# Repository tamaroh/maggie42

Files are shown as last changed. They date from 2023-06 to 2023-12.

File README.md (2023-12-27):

# maggie42
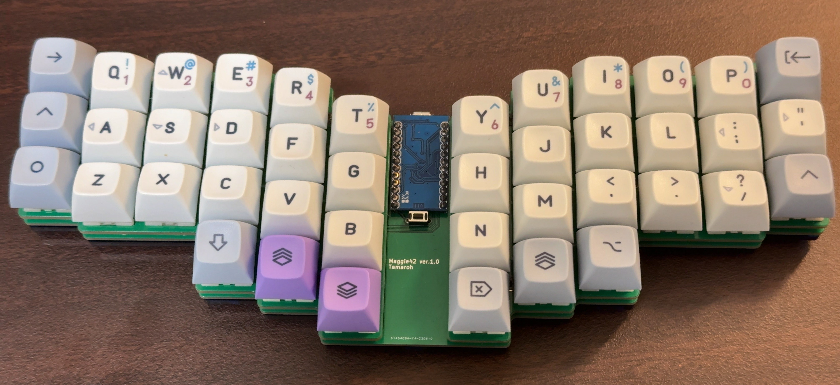
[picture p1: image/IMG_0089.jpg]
maggie42

maggie42は  
カスタムキーボードです。
- 左右対称カラムスタッガード
- 自然にハの字に手が配置される
- 傾けないレイアウトでキーの隙間がない
- 小指から弧を描く配列
- Pro Microに対応
- All 1Uレイアウト

## 必要なもの
|品名|数量|備考|入手先|
|----|----|----|----|
|PCB|1枚|
|キープレート|2枚|裏表はありません|
|ボトムプレート|1枚|
|M2ネジ 5mm|20本||遊舎工房など
|M2スペーサー 7mm|10個||遊舎工房など
|Pro Micro|1個|すべての互換品については動作を保障しません*|遊舎工房など
|ピンヘッダー|12Pin x 2個|コンスルー対応|遊舎工房など
|タクトスイッチ|1個||遊舎工房など
|USBケーブル|1本||遊舎工房など
|ダイオード|42個|SMD/スルーホール対応|遊舎工房など
|キーソケット|42個|Cherry MX互換のみ対応|遊舎工房など
|キースイッチ|42個|Cherry MX互換のみ対応|遊舎工房など
|キーキャップ|セット|すべて1Uです|遊舎工房など

* 厚さの異なるPro Micro互換品（USB-Cコネクタのタイプ）などの場合、コンスルーでは動作を保障できません。
  確実に接続できるピンヘッダ接続をおすすめします。

## 必要な工具
- はんだごて
- コテ台、コテ先クリーナー
- はんだ
- 精密ドライバー
- ピンセット

## 必要なソフトウェア
- [qmk toolbox](https://github.com/qmk/qmk_toolbox/releases)

## 制作手順
手順は人により異なりますが
1. Pro Microにファームウェアを書き込みます。
  - QMK Toolboxを起動し、書き込むファームウェア（下記参照）を選択しておきます。
  - USBをPCに接続して、リセットスイッチを押します。
  - 書き込み可能状態になったら、Flashボタンをクリックして書き込みます。
  - 書き込みが完了したらUSBケーブルを接続し直します。
2. ダイオードを半田付けします。SMDの場合縦線が入っている方の端子、スルーホールの場合黒い線がある方の端子を、基板上の縦線がある側に接続してください。
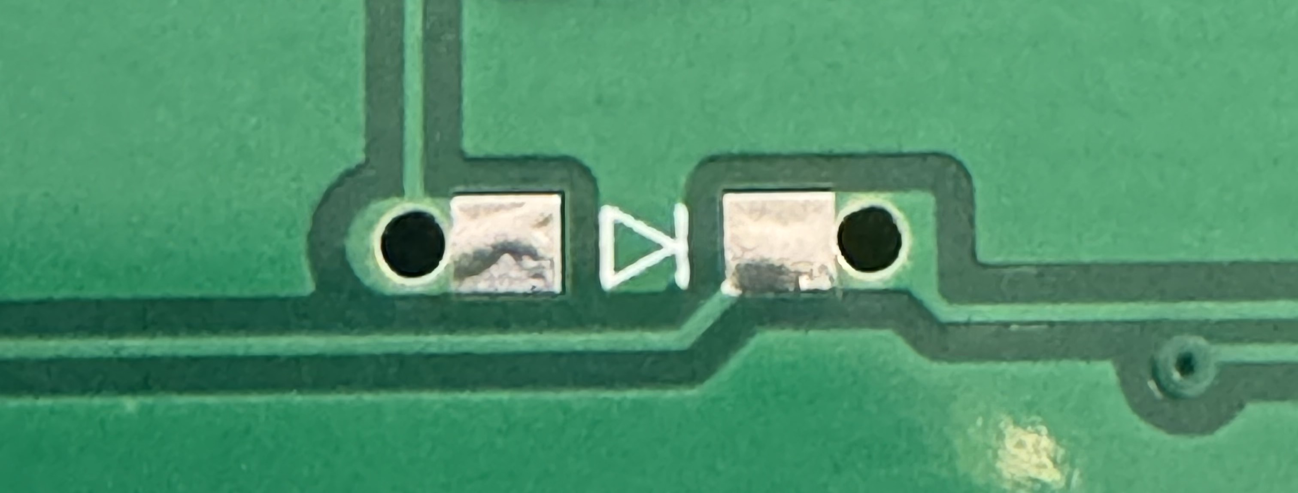
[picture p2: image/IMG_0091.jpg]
diode_before
   
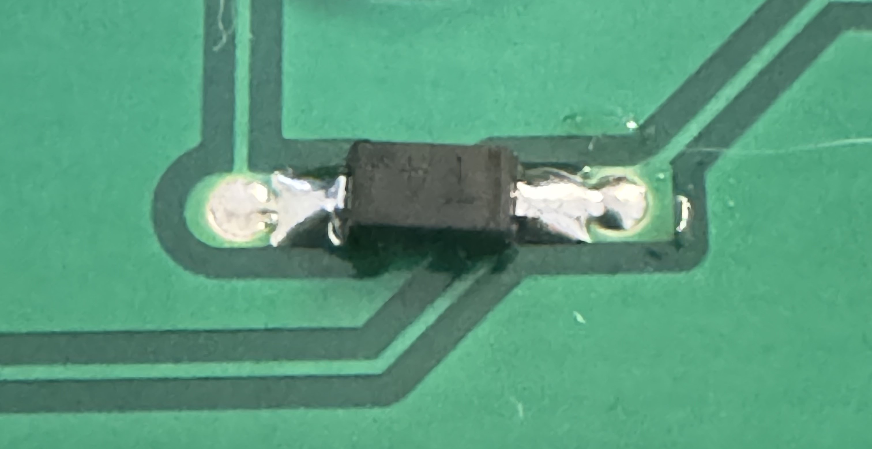
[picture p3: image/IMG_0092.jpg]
diode_after
   
3. Pro Microを用意します。
   コンスルーを使用する場合は基板に差し込んでから、適切にPro Microに半田付けしてください。
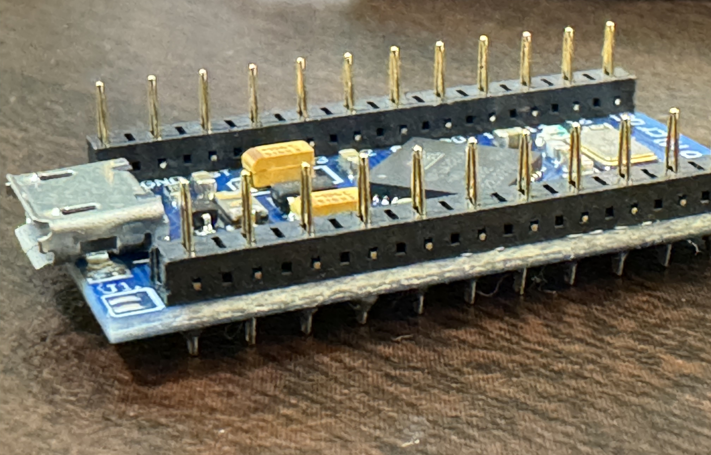
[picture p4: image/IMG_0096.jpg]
conthrough
   
   ピンヘッダを使用する場合は向きや表裏を間違えないようにします。
   ※USB-Cタイプなど、USBコネクタ部の場合はピンヘッダの高さが合わなかったり、コンスルーが抜けやすくなる可能性があります。
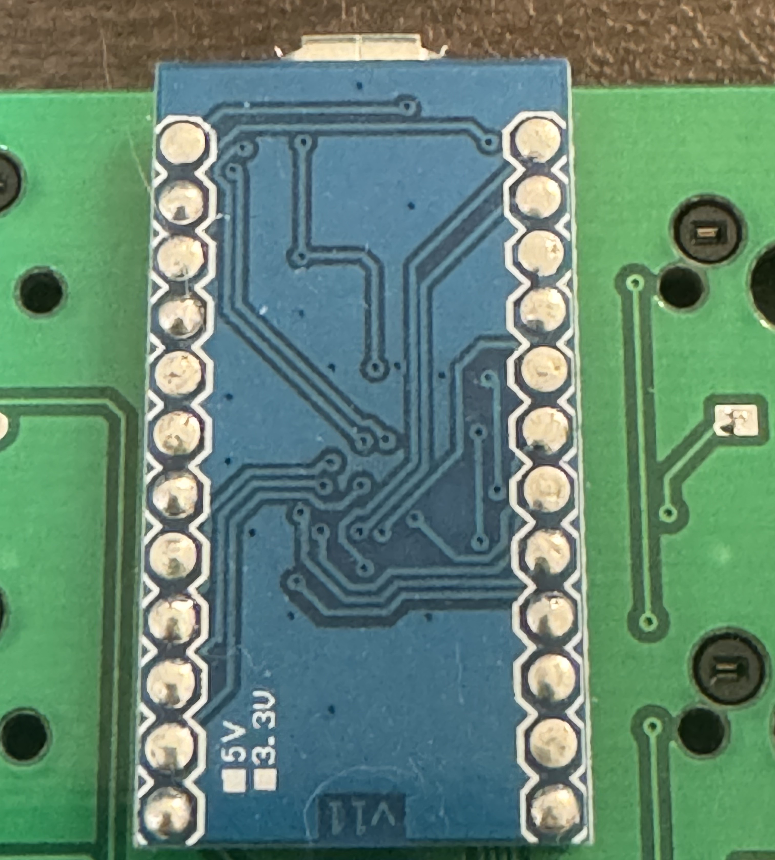
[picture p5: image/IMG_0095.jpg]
   
4. ソケットを半田付けします。シルク印刷に合わせて、スイッチの穴を塞がないようにします。
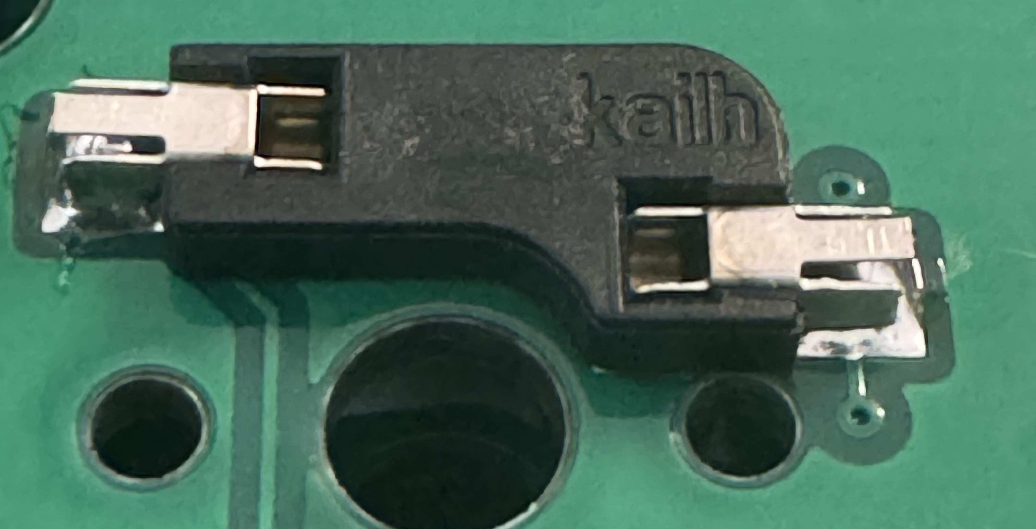
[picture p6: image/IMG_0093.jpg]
   
5. リセットスイッチを半田付けします。
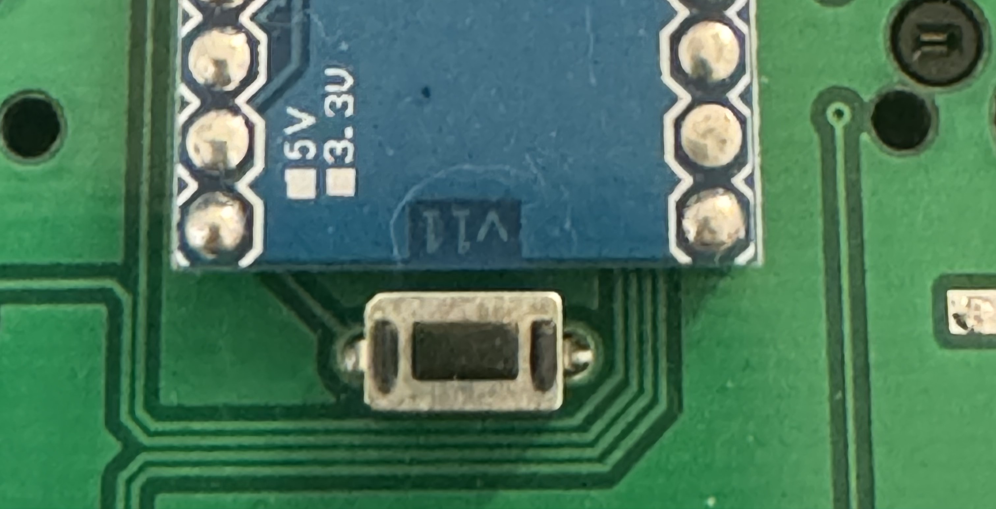
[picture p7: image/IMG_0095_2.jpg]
resetswitch
   
6. キースイッチを4個程度、先にキープレートに差し込みます。
7. 基板と接続します。スイッチのピンが曲がらないように上からまっすぐ抑えます。
8. 残りのスイッチを差し込みます。ソケットとスイッチを指で挟み込むようにして、ソケットに確実に差し込みます。
9. 
10. PCBとキースイッチを接続します。
11. キーキャップを乗せます。
12. できあがり

## ファームウェアについて
ファームウェアは以下にあります。
https://github.com/tamaroh/maggie42/tree/main/firmware
|種別|ファイル名|備考
|----|----|----|
|QMK|maggie42_default.hex||
|VIA|maggie42_via.json||
|VIAL|maggie42_vial.hex|

ソースコードはこちら：https://github.com/tamaroh/qmk_firmware/tree/tamaroh/keyboards/tamaroh/maggie42
## 注意事項
- 自作キーボードについての知識がある方を対象としています。
- 非販売品につき、サポートは対象外としております。

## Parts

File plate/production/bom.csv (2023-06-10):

Designator | Footprint | Quantity | Value | LCSC Part #
SW1, SW10, SW11, SW12, SW13, SW14, SW15, SW16, SW17, SW18, SW19, SW2, SW20, SW21, SW3, SW4, SW5, SW6, SW7, SW8, SW9 | SW_Hole | 21 | SW_PUSH

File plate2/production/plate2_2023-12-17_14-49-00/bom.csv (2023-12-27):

Designator | Footprint | Quantity | Value | LCSC Part #
SW1, SW10, SW11, SW12, SW13, SW14, SW15, SW16, SW17, SW18, SW19, SW2, SW20, SW21, SW22, SW23, SW24, SW25, SW26, SW27, SW28, SW29, SW3, SW30, SW31, SW32, SW33, SW34, SW35, SW36, SW37, SW38, SW39, SW4, SW40, SW41, SW42, SW5, SW6, SW7, SW8, SW9 | Switch_Hole | 42 | SW_PUSH

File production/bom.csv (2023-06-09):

Designator | Footprint | Quantity | Value | LCSC Part #
D1, D10, D11, D12, D13, D14, D15, D16, D17, D18, D19, D2, D20, D21, D22, D23, D24, D25, D26, D27, D28, D29, D3, D30, D31, D32, D33, D34, D35, D36, D37, D38, D39, D4, D40, D41, D42, D5, D6, D7, D8, D9 | D3_TH_SMD_v2 | 42 | 1N4148W
RSSW0 | ResetSW_1side | 1 | RESETSW
SW1, SW10, SW11, SW12, SW13, SW14, SW15, SW16, SW17, SW18, SW19, SW2, SW20, SW21, SW22, SW23, SW24, SW25, SW26, SW27, SW28, SW29, SW3, SW30, SW31, SW32, SW33, SW34, SW35, SW36, SW37, SW38, SW39, SW4, SW40, SW41, SW42, SW5, SW6, SW7, SW8, SW9 | CherryMX_Hotswap | 42 | SW_PUSH
U1 | ProMicro_v3 | 1 | ProMicro

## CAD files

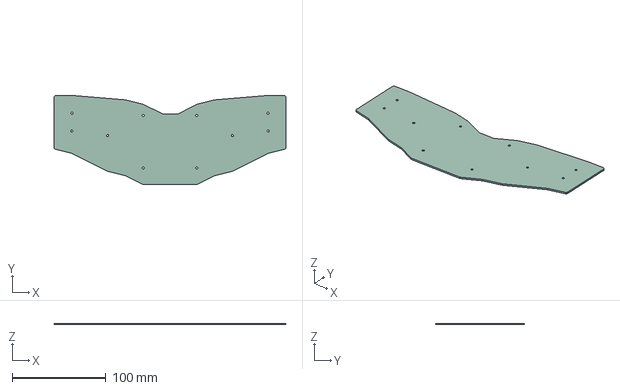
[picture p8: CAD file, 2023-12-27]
plate2/bottomplate.step
247.7 x 95.2 x 1.58 mm

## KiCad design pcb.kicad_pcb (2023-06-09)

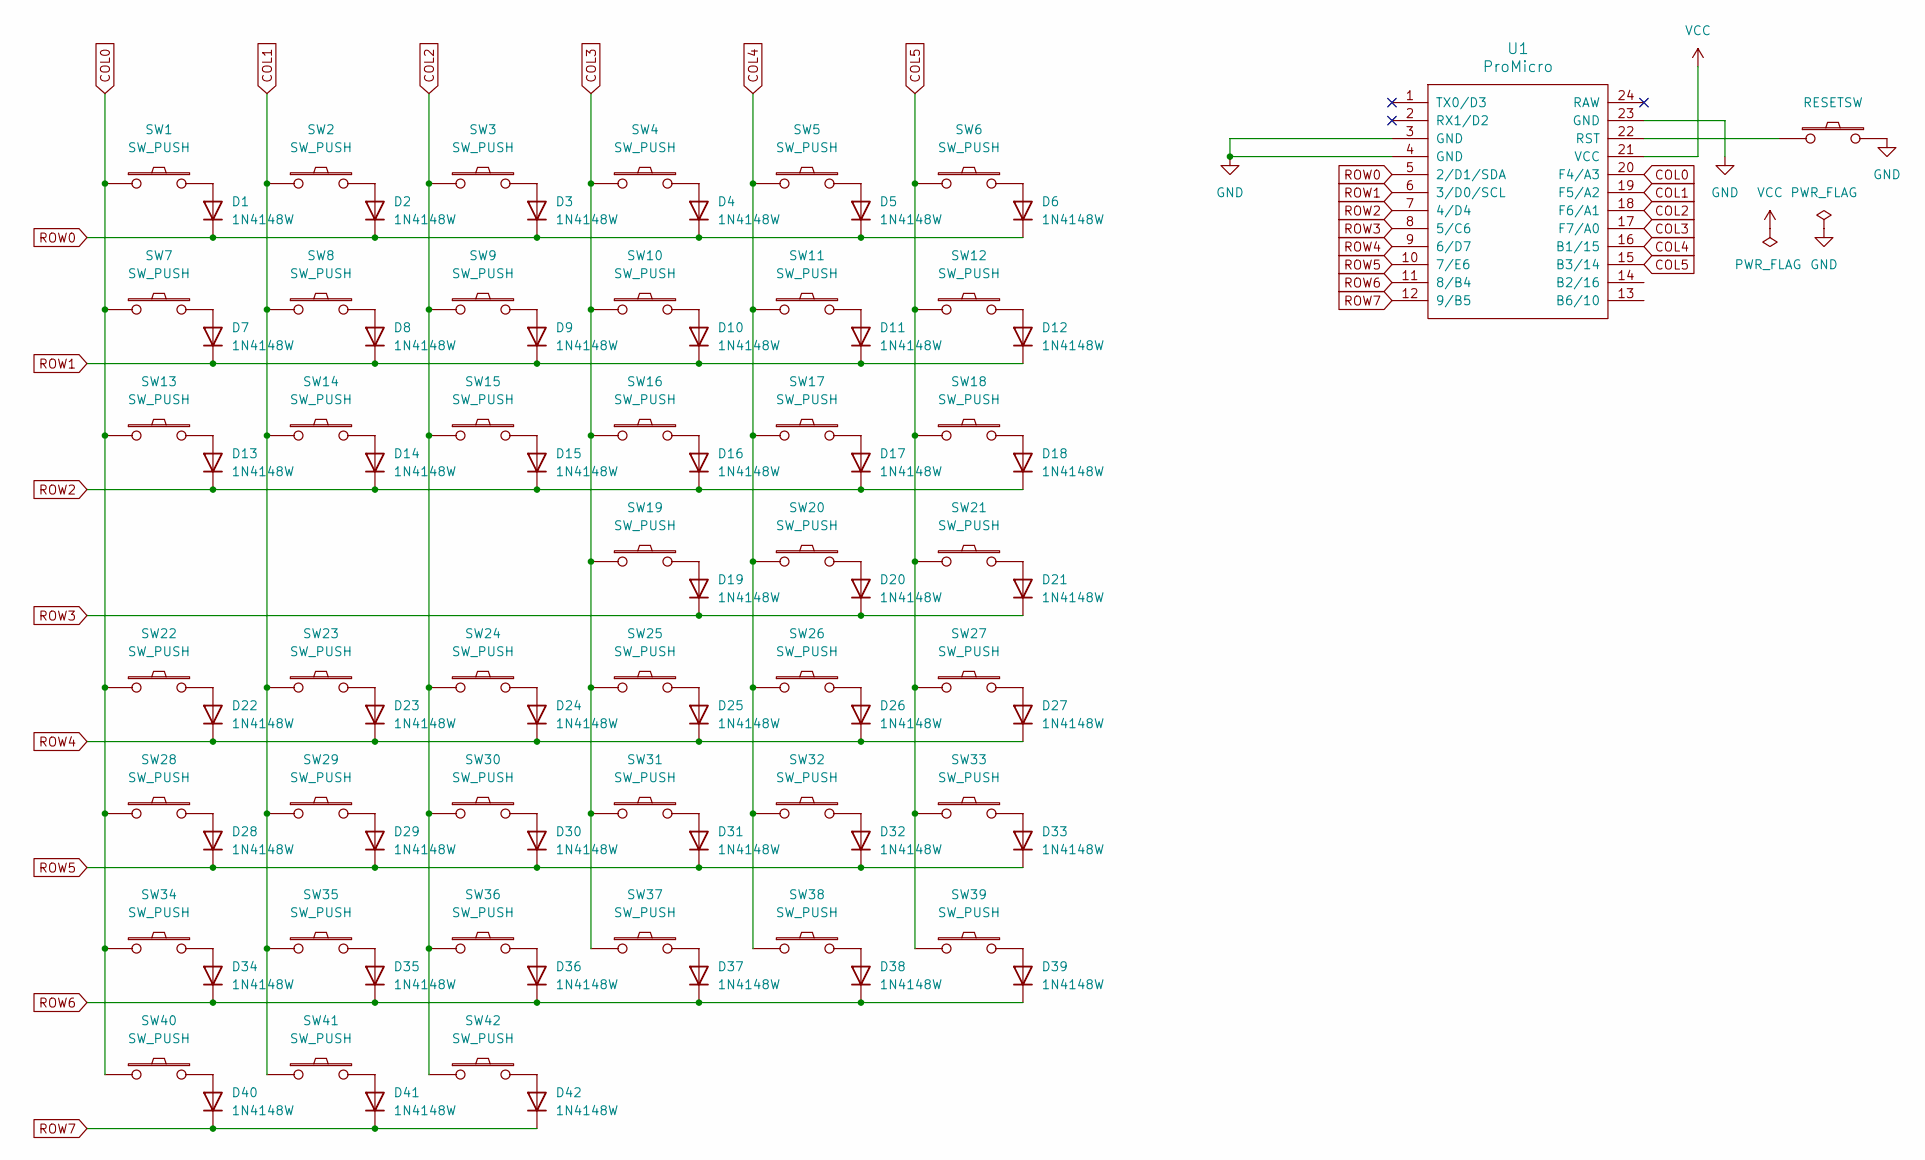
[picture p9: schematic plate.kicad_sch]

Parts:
D1, D2, D3, D4, D5, D6, D7, D8, D9, D10, D11, D12, D13, D14, D15, D16, D17, D18, D19, D20, D21, D22, D23, D24, D25, D26, D27, D28, D29, D30, D31, D32, D33, D34, D35, D36, D37, D38, D39, D40, D41, D42: 1N4148W; D3_TH_SMD_v2
RSSW0: RESETSW; ResetSW_1side
SW1, SW2, SW3, SW4, SW5, SW6, SW7, SW8, SW9, SW10, SW11, SW12, SW13, SW14, SW15, SW16, SW17, SW18, SW19, SW20, SW21, SW22, SW23, SW24, SW25, SW26, SW27, SW28, SW29, SW30, SW31, SW32, SW33, SW34, SW35, SW36, SW37, SW38, SW39, SW40, SW41, SW42: SW_PUSH; CherryMX_Hotswap
U1: ProMicro; ProMicro_v3.5

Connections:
COL0: SW1.1, SW7.1, SW13.1, SW22.1, SW28.1, SW34.1, SW40.1, U1.20 (F4/A3)
COL1: SW2.1, SW8.1, SW14.1, SW23.1, SW29.1, SW35.1, SW41.1, U1.19 (F5/A2)
COL2: SW3.1, SW9.1, SW15.1, SW24.1, SW30.1, SW36.1, SW42.1, U1.18 (F6/A1)
COL3: SW4.1, SW10.1, SW16.1, SW19.1, SW25.1, SW31.1, SW37.1, U1.17 (F7/A0)
COL4: SW5.1, SW11.1, SW17.1, SW20.1, SW26.1, SW32.1, SW38.1, U1.16 (B1/15)
COL5: SW6.1, SW12.1, SW18.1, SW21.1, SW27.1, SW33.1, SW39.1, U1.15 (B3/14)
GND: RSSW0.2, U1.3 (GND), U1.4 (GND), U1.23 (GND)
unnamed: D1.2 (A), SW1.2
unnamed: D2.2 (A), SW2.2
unnamed: D3.2 (A), SW3.2
unnamed: D4.2 (A), SW4.2
unnamed: D5.2 (A), SW5.2
unnamed: D6.2 (A), SW6.2
unnamed: D7.2 (A), SW7.2
unnamed: D8.2 (A), SW8.2
unnamed: D9.2 (A), SW9.2
unnamed: D10.2 (A), SW10.2
unnamed: D11.2 (A), SW11.2
unnamed: D12.2 (A), SW12.2
unnamed: D13.2 (A), SW13.2
unnamed: D14.2 (A), SW14.2
unnamed: D15.2 (A), SW15.2
unnamed: D16.2 (A), SW16.2
unnamed: D17.2 (A), SW17.2
unnamed: D18.2 (A), SW18.2
unnamed: D19.2 (A), SW19.2
unnamed: D20.2 (A), SW20.2
unnamed: D21.2 (A), SW21.2
unnamed: D22.2 (A), SW22.2
unnamed: D23.2 (A), SW23.2
unnamed: D24.2 (A), SW24.2
unnamed: D25.2 (A), SW25.2
unnamed: D26.2 (A), SW26.2
unnamed: D27.2 (A), SW27.2
unnamed: D28.2 (A), SW28.2
unnamed: D29.2 (A), SW29.2
unnamed: D30.2 (A), SW30.2
unnamed: D31.2 (A), SW31.2
unnamed: D32.2 (A), SW32.2
unnamed: D33.2 (A), SW33.2
unnamed: D34.2 (A), SW34.2
unnamed: D35.2 (A), SW35.2
unnamed: D36.2 (A), SW36.2
unnamed: D37.2 (A), SW37.2
unnamed: D38.2 (A), SW38.2
unnamed: D39.2 (A), SW39.2
unnamed: D40.2 (A), SW40.2
unnamed: D41.2 (A), SW41.2
unnamed: D42.2 (A), SW42.2
unnamed: RSSW0.1, U1.22 (RST)
ROW0: D1.1 (K), D2.1 (K), D3.1 (K), D4.1 (K), D5.1 (K), D6.1 (K), U1.5 (2/D1/SDA)
ROW1: D7.1 (K), D8.1 (K), D9.1 (K), D10.1 (K), D11.1 (K), D12.1 (K), U1.6 (3/D0/SCL)
ROW2: D13.1 (K), D14.1 (K), D15.1 (K), D16.1 (K), D17.1 (K), D18.1 (K), U1.7 (4/D4)
ROW3: D19.1 (K), D20.1 (K), D21.1 (K), U1.8 (5/C6)
ROW4: D22.1 (K), D23.1 (K), D24.1 (K), D25.1 (K), D26.1 (K), D27.1 (K), U1.9 (6/D7)
ROW5: D28.1 (K), D29.1 (K), D30.1 (K), D31.1 (K), D32.1 (K), D33.1 (K), U1.10 (7/E6)
ROW6: D34.1 (K), D35.1 (K), D36.1 (K), D37.1 (K), D38.1 (K), D39.1 (K), U1.11 (8/B4)
ROW7: D40.1 (K), D41.1 (K), D42.1 (K), U1.12 (9/B5)
VCC: U1.21 (VCC)

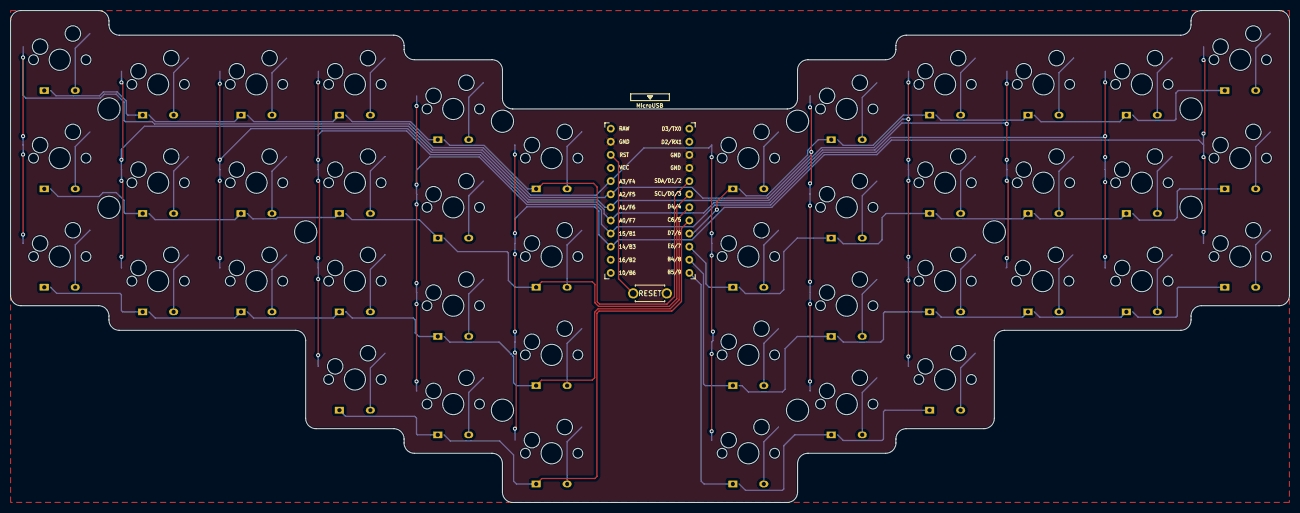
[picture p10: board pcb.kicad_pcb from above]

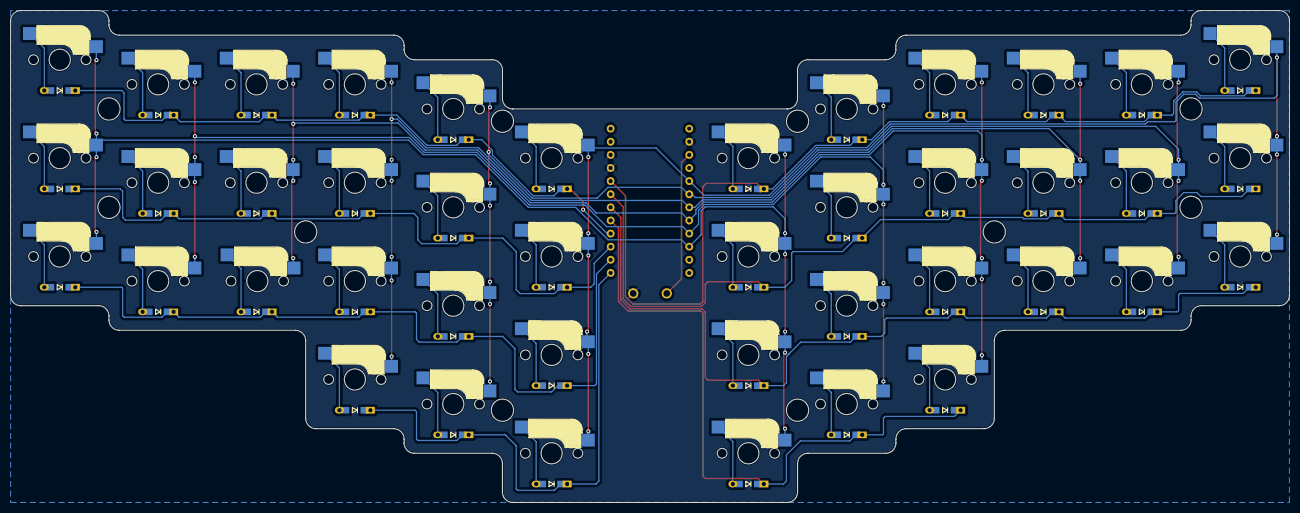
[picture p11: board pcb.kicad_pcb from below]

Board: 2 copper layers, 247.7 x 95.2 mm, 96 parts (42 on the bottom side), 58 nets.

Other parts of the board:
Ref**: Val**; spacer_m2
Ref**#2, Ref**#3, Ref**#4, Ref**#5, Ref**#6, Ref**#7, Ref**#8, Ref**#9, Ref**#10: Val**; spacer_m2

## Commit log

2023-06-05 create circuit
    [pcb.kicad_sch]
2023-06-05 rename repo and folder
    [pcb.kicad_sch]
2023-06-05 fixed switch numbering
    [pcb.kicad_sch]
2023-06-05 assigned footprint
    [pcb.kicad_sch]
2023-06-06 fixed lines
    [pcb.kicad_pcb]
2023-06-06 refactored wiring
    [pcb.kicad_pcb]
2023-06-07 set hole
    [pcb.kicad_pcb]
2023-06-09 create garbar file
    [bom.csv, designators.csv, pcb.kicad_pcb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]
2023-06-10 changed top-plate half-size
    [bom.csv, designators.csv, plate.kicad_pcb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]
2023-06-13 added bottom plate
    [bottom_plate.kicad_pcb, bottom_plate.kicad_sch]
2023-12-27 added test svg files
    [bom.csv, bottomplate.kicad_pcb, bottomplate.step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]
